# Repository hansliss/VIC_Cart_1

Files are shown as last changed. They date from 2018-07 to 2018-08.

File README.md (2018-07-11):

# VIC_Cart_1
A basic programmable RAM/ROM expansion for VIC-20

RAM is handled by an KM681000CLG-5L, 128kx8 static RAM
~RAM1,~RAM2,~RAM3 are NAND:ed together, so the 3k area is handled as a single block
A0-A13 are provided by the cartridge port, while A14 and A15 are connected to ~BLK2 and ~BLK1, respectively.
With 8k blocks (using 13 address lines)

NOTE: The RAM addressing is incorrect and needs to be fixed!

blk	addresses	
0	0400-0fff       01111  01
1	2000-3fff	10111  11
2	4000-5fff	11011  00
3	6000-7fff	11101  01
5	a000-bfff	11110  11

U4C: 3-input AND
U5D: 2-input OR

BLK0 OR BLK2 OR BLK3 = A13
BLK2 = A14

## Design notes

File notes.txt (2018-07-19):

C1: https://www.elfa.se/en/capacitor-100-nf-25-vdc-0603-rnd-components-rnd-1500603y104z250nt/p/30086612
C2, C3: https://www.elfa.se/en/capacitor-22-pf-50-vdc-0603-rnd-components-rnd-1500603n220f500nt/p/30086539
C4: https://www.elfa.se/en/aluminium-electrolytic-capacitor-10-uf-16-20-hc-panasonic-industry-europe-eeehc1c100r/p/30108103
C5-C11: https://www.elfa.se/en/capacitor-uf-16-0603-kemet-c0603x104k4ractu/p/30111165
D1: https://www.elfa.se/en/small-signal-diode-do-213aa-diotec-bav103/p/30110670
R1-R3: https://www.elfa.se/en/smd-resistor-metal-thin-film-10-kohm-panasonic-industry-europe-era3aeb103v/p/16015687
U4: https://www.elfa.se/en/logic-ic-so-16-sn74hc148-texas-instruments-sn74hc148d/p/17379828
U5, U6: https://www.elfa.se/en/logic-ic-so-14-nxp-74hc21d/p/17390727
U7,U8,U9: https://www.elfa.se/en/logic-ic-so-14-sn74hc32-texas-instruments-sn74hc32dr/p/30023025
Y1: https://www.elfa.se/en/quartz-hc49us-16-mhz-auris-16-00000m-hc49us-30-30-d32/p/17452832

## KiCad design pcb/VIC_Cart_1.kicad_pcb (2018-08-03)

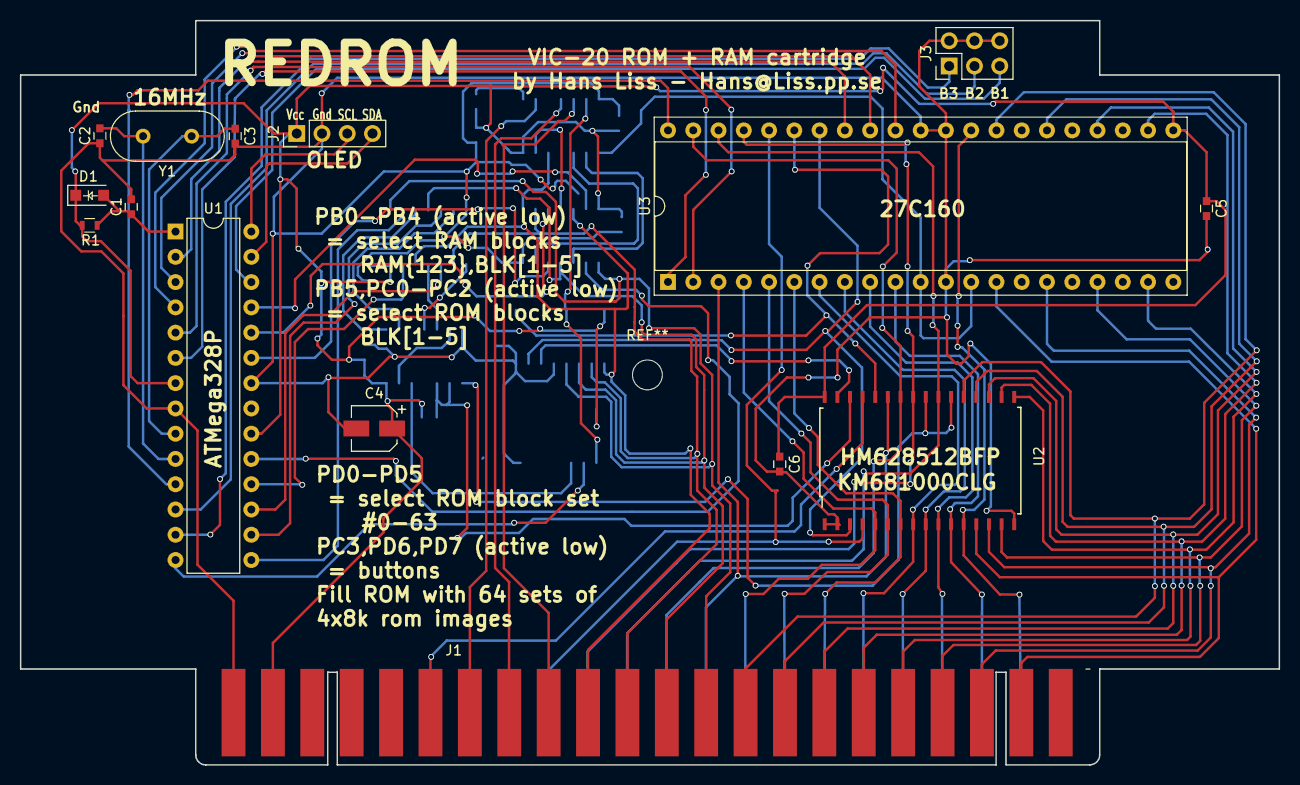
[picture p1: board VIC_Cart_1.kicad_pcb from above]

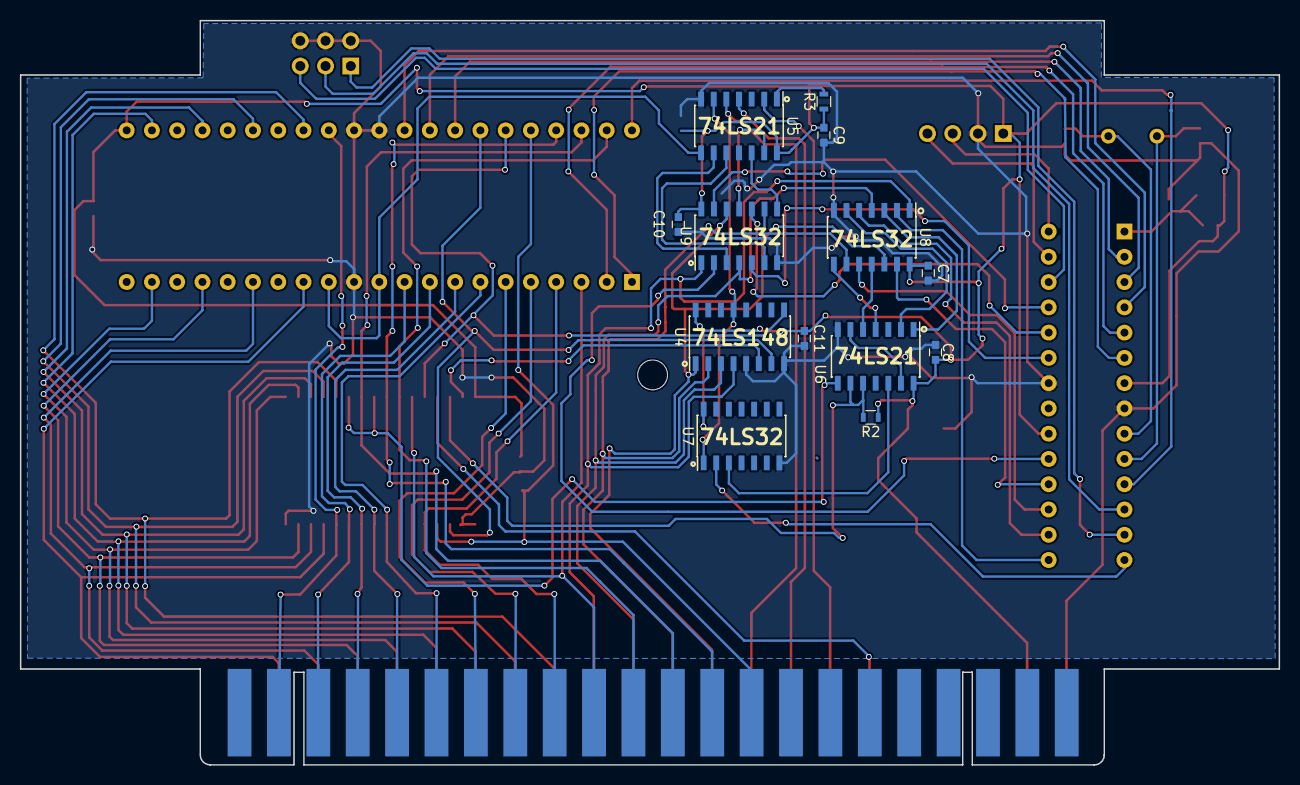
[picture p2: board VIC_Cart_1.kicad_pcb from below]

Board: 2 copper layers, 126.5 x 74.8 mm, 28 parts (13 on the bottom side), 72 nets.

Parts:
C1: 100nf; C_0603
C2, C3: 22pf; C_0603
C4: 10uf; CP_Elec_4x5.8
C5, C6, C7, C8, C9, C10, C11: 0.1uf; C_0603
D1: 1N4148; D_SOD-123F
J1: VIC-20_Expansion_Port; VIC_EXP
J2: I2C Display; Pin_Header_Straight_1x04_Pitch2.54mm
J3: Buttons; Pin_Header_Straight_2x03_Pitch2.54mm
R1, R2, R3: 10k; R_0603
U1: ATMEGA328P-PU; DIP-28_W7.62mm
U2: HM628512BFP-5; SOP-32_14.12x20.87mm_Pitch1.27mm
U3: M27C160; DIP-42_W15.24mm_Socket
U4: 74LS148; SOIC-16_3.9x9.9mm_Pitch1.27mm
U5, U6: 74LS21; SOIC-14_3.9x8.7mm_Pitch1.27mm
U7, U8, U9: 74LS32; SOIC-14_3.9x8.7mm_Pitch1.27mm
Y1: 16MHz; Crystal_HC49-4H_Vertical

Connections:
/OLED_SCL: J2.3, U1.28
/OLED_SDA: J2.4, U1.27
/V_RW: J1.17, U2.29
/~BLK1: J1.10, U4.4, U8.1, U9.1
/~BLK2: J1.11, U4.3, U8.4, U9.4
/~BLK3: J1.12, U4.2, U8.9, U9.9
/~BLK5: J1.13, U4.1, U8.12, U9.12
/~BUTTON1: J3.5, U1.26
/~BUTTON2: J3.3, U1.12
/~BUTTON3: J3.1, U1.13
/~RAM: U4.13, U5.6, U7.1
/~RESET: C1.1, D1.2, R1.2, U1.1
/~SEL_RAM_3k: U1.14, U7.2
/~SEL_RAM_BLK1: U1.15, U8.2
/~SEL_RAM_BLK2: U1.16, U8.5
/~SEL_RAM_BLK3: U1.17, U8.10
/~SEL_RAM_BLK5: U1.18, U8.13
/~SEL_ROM_BLK1: U1.19, U9.2
/~SEL_ROM_BLK2: U1.23, U9.5
/~SEL_ROM_BLK3: U1.24, U9.10
/~SEL_ROM_BLK5: U1.25, U9.13
A0: J1.B, U2.12, U3.30
A1: J1.C, U2.11, U3.10
A2: J1.D, U2.10, U3.9
A3: J1.E, U2.9, U3.8
A4: J1.F, U2.8, U3.7
A5: J1.H, U2.7, U3.6
A6: J1.J, U2.6, U3.5
A7: J1.K, U2.5, U3.4
A8: J1.L, U2.27, U3.3
A9: J1.M, U2.26, U3.41
A10: J1.N, U2.23, U3.40
A11: J1.P, U2.25, U3.39
A12: J1.R, U2.4, U3.38
BA0: U2.28, U3.37, U4.9
BA1: U2.3, U3.36, U4.7
BA2: U2.31, U4.6
D0: J1.2, U2.13, U3.14
D1: J1.3, U2.14, U3.16
D2: J1.4, U2.15, U3.18
D3: J1.5, U2.17, U3.20
D4: J1.6, U2.18, U3.23
D5: J1.7, U2.19, U3.25
D6: J1.8, U2.20, U3.27
D7: J1.9, U2.21, U3.29
GND: C1.2, C2.1, C3.2, C4.2, C5.2, C6.2, C7.2, C8.2, C9.2, C10.2, C11.2, J1.22, J2.2, J3.2, J3.4, J3.6, U1.8, U1.22, U2.1, U2.2, U2.16, U3.12, U3.31, U3.32, U4.5, U4.8, U5.7, U6.7, U7.7, U8.7, U9.7
unnamed: C2.2, U1.10, Y1.2
unnamed: C3.1, U1.9, Y1.1
unnamed: J1.14, U5.5
unnamed: J1.15, U5.4
unnamed: J1.16, U5.2
unnamed: R2.2, U2.30, U6.9, U6.10
unnamed: R3.2, U5.1
unnamed: U2.22, U2.24, U6.8
unnamed: U3.11, U3.13, U5.8
unnamed: U5.9, U9.3
unnamed: U5.10, U9.6
unnamed: U5.12, U9.8
unnamed: U5.13, U9.11
unnamed: U6.1, U8.3
unnamed: U6.2, U8.6
unnamed: U6.4, U8.8
unnamed: U6.5, U8.11
unnamed: U6.12, U7.3
unnamed: U6.6, U6.13
RB0: U1.2, U3.35
RB1: U1.3, U3.34
RB2: U1.4, U3.33
RB3: U1.5, U3.2
RB4: U1.6, U3.1
RB5: U1.11, U3.42
VCC: C4.1, C5.1, C6.1, C7.1, C8.1, C9.1, C10.1, C11.1, D1.1, J1.21, J2.1, R1.1, R2.1, R3.1, U1.7, U1.20, U2.32, U3.22, U4.16, U5.14, U6.14, U7.14, U8.14, U9.14

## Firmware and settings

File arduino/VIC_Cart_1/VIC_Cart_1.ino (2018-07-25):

#include <Adafruit_GFX.h>
#include <Adafruit_SPITFT.h>
#include <Adafruit_SPITFT_Macros.h>
#include <gfxfont.h>
#include <EEPROM.h>

#include <Adafruit_SSD1306.h>


int ram0=8;
int ram1=9;
int ram2=10;
int ram3=11;
int ram5=12;

int rom1=13;
int rom2=14;
int rom3=15;
int rom5=16;

int rb0=0;
int rb1=1;
int rb2=2;
int rb3=3;
int rb4=4;
int rb5=5;

int but1=17;
int but2=6;
int but3=7;

unsigned long debounceDelay = 100;

int rammode=0;

// OLED display TWI address
#define OLED_ADDR   0x3C

// reset pin not used on 4-pin OLED module
Adafruit_SSD1306 display(-1);  // -1 = no reset pin

// 128 x 64 pixel display
#if (SSD1306_LCDHEIGHT != 64)
#error("Height incorrect, please fix Adafruit_SSD1306.h!");
#endif

int ramModes[][2] = {
  {0, 0},
  {3, 1},
  {8, 2},
  {11,3},
  {16,6},
  {19,7},
  {24,14},
  {27,15},
  {32,30},
  {35,31}
};

int numRamModes=(sizeof(ramModes)/sizeof(int[2]));

int currentRamMode=0;

int setRamMode(int mode) {
  static int lastMode=-1;
  int bits=ramModes[mode][1];
  if (mode != lastMode) {
    lastMode=mode;
    EEPROM.write(0, mode);
    digitalWrite(ram0, (bits & 1)?LOW:HIGH); // outputs are active low!
    digitalWrite(ram1, (bits & 2)?LOW:HIGH);
    digitalWrite(ram2, (bits & 4)?LOW:HIGH);
    digitalWrite(ram3, (bits & 8)?LOW:HIGH);
    digitalWrite(ram5, (bits & 16)?LOW:HIGH);
  }
}

struct rm_s {
  char *text;
  int bits;
} romModes[]= {
  {"None", 0},
  {"BLK2,3", 6},
  {"BLK5", 8},
  {"BLK1,5", 9},
  {"BLK3", 4},
  {"BLK3,5", 12}
};

int numRomModes=(sizeof(romModes)/sizeof(struct rm_s));

int currentRomMode=0;

int setRomMode(int mode) {
  static int lastMode=-1;
  int bits=romModes[mode].bits;
  if (mode != lastMode) {
    lastMode=mode;
    EEPROM.write(1, mode);
    digitalWrite(rom1, (bits & 1)?LOW:HIGH); // outputs are active low!
    digitalWrite(rom2, (bits & 2)?LOW:HIGH);
    digitalWrite(rom3, (bits & 4)?LOW:HIGH);
    digitalWrite(rom5, (bits & 8)?LOW:HIGH);
  }
}

int numRomBanks=9;
int currentRomBank=0;

int setRomBank(int bank) {
  static int lastBank=-1;
  if (bank != lastBank) {
    lastBank=bank;
    EEPROM.write(2, bank);
    digitalWrite(rb0, (bank & 1)?HIGH:LOW); // outputs are active low!
    digitalWrite(rb1, (bank & 2)?HIGH:LOW);
    digitalWrite(rb2, (bank & 4)?HIGH:LOW);
    digitalWrite(rb3, (bank & 8)?HIGH:LOW);
    digitalWrite(rb4, (bank & 16)?HIGH:LOW);
    digitalWrite(rb5, (bank & 32)?HIGH:LOW);
  }
}

void displayModes() {
    static char buf[16];
    int ramSize=ramModes[currentRamMode][0];
    char *romConf=romModes[currentRomMode].text;
    display.clearDisplay();
    display.setTextSize(1);
    display.setTextColor(WHITE);
    display.setCursor(27,10);
    sprintf(buf, "RAM: %dkB", ramSize);
    display.print(buf);
    display.setCursor(27,20);
    sprintf(buf, "ROM: %s", romConf);
    display.print(buf);
    display.setCursor(27,30);
    sprintf(buf, "Bank: %d", currentRomBank);
    display.print(buf);
    display.display();
}

void setup() {
  currentRamMode = EEPROM.read(0);
  currentRomMode = EEPROM.read(1);
  currentRomBank = EEPROM.read(2);
  pinMode(ram0, OUTPUT);
  pinMode(ram1, OUTPUT);
  pinMode(ram2, OUTPUT);
  pinMode(ram3, OUTPUT);
  pinMode(ram5, OUTPUT);
  pinMode(rom1, OUTPUT);
  pinMode(rom2, OUTPUT);
  pinMode(rom3, OUTPUT);
  pinMode(rom5, OUTPUT);
  pinMode(rb0, OUTPUT);
  pinMode(rb1, OUTPUT);
  pinMode(rb2, OUTPUT);
  pinMode(rb3, OUTPUT);
  pinMode(rb4, OUTPUT);
  pinMode(rb5, OUTPUT);
  pinMode(but1, INPUT_PULLUP);
  pinMode(but2, INPUT_PULLUP);
  pinMode(but3, INPUT_PULLUP);
  digitalWrite(rom1, HIGH);
  digitalWrite(rom2, HIGH);
  digitalWrite(rom3, HIGH);
  digitalWrite(rom5, HIGH);
  // put your setup code here, to run once:
  display.begin(SSD1306_SWITCHCAPVCC, 0x3C);
  display.clearDisplay();
  display.display();
  setRamMode(currentRamMode);
  setRomMode(currentRomMode);
  setRomBank(currentRomBank);
  displayModes();
}

int buttonWithDeBounce(int button, int *curState, long *lastTime) {
  int r=0;
  int reading = digitalRead(button);
  if ((millis() - *lastTime) > debounceDelay) {
    if (reading != *curState) {
      *curState=reading;
      r = (*curState == LOW);
      *lastTime = millis();
    }
  }
  return r;
}

void loop() {
  static int but1State=HIGH;
  static int but2State=HIGH;
  static int but3State=HIGH;
  static long lastDebounceTimeBut1=0;
  static long lastDebounceTimeBut2=0;
  static long lastDebounceTimeBut3=0;
  if (buttonWithDeBounce(but1, &but1State, &lastDebounceTimeBut1)) {
    currentRamMode = (currentRamMode + 1) % numRamModes;
    setRamMode(currentRamMode);
    displayModes();
  }
  if (buttonWithDeBounce(but2, &but2State, &lastDebounceTimeBut2)) {
    currentRomMode = (currentRomMode + 1) % numRomModes;
    setRomMode(currentRomMode);
    displayModes();
  }
  if (buttonWithDeBounce(but3, &but3State, &lastDebounceTimeBut3)) {
    currentRomBank = (currentRomBank + 1) % numRomBanks;
    setRomBank(currentRomBank);
    displayModes();
  }
}

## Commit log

2018-07-10 Initial import
    [VIC_Cart_1-B.Cu.gbr, VIC_Cart_1-B.Paste.gbr, VIC_Cart_1-B.SilkS.gbr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]
2018-07-11 Added A13/A14 to RAM for correct block addressing
    [VIC_Cart_1-B.Cu.gbr, VIC_Cart_1-B.Fab.gbr, VIC_Cart_1-B.Mask.gbr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]
2018-07-11 Working on the RAM addressing scheme - currently incorrect
    [VIC_Cart_1.sch]
2018-07-13 Massive redesign to fix block address encoding from the expansion port signals
    [VIC_Cart_1-B.Cu.gbr, VIC_Cart_1-B.Fab.gbr, VIC_Cart_1-B.Mask.gbr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]
2018-07-13 Added Connectors lib Cleaned up libs by removing unused components
2018-07-13 Added Footprint library to project Added explanatory text to PCB
    [VIC_Cart_1-B.Cu.gbr, VIC_Cart_1-B.Fab.gbr, VIC_Cart_1-B.Mask.gbr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]
2018-07-14 Added back ground plane
    [VIC_Cart_1-B.Cu.gbr, VIC_Cart_1-B.Fab.gbr, VIC_Cart_1-B.Mask.gbr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]
2018-07-14 Switched around BLK[1-5] to encoder to put ROM blocks in correct order.
    [VIC_Cart_1-B.Cu.gbr, VIC_Cart_1-B.Fab.gbr, VIC_Cart_1-B.Mask.gbr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]
2018-07-17 Minor change
    [VIC_Cart_1-B.Cu.gbr, VIC_Cart_1-B.Fab.gbr, VIC_Cart_1-B.Mask.gbr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]
2018-07-17 Moved PCB files to subdirectory
    [VIC_Cart_1-B.Cu.gbr, VIC_Cart_1-B.Fab.gbr, VIC_Cart_1-B.Mask.gbr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]
2018-07-24 Arduino code added
2018-07-29 Changed pads to pin header footprint for buttons Inverted BLK inputs to encoder to correct addressing error Added component values to silkscreen
    [VIC_Cart_1-B.CrtYd.gbr, VIC_Cart_1-B.Cu.gbr, VIC_Cart_1-B.Fab.gbr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]
2018-07-29 No change
    [VIC_Cart_1.kicad_pcb, VIC_Cart_1.sch]
2018-07-31 Added mounting hole Added title
    [VIC_Cart_1-B.CrtYd.gbr, VIC_Cart_1-B.Cu.gbr, VIC_Cart_1-B.Fab.gbr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]
2018-07-31 Moved button pin header to the right Changed outline to match existing (large) carts, e.g. 16k expansion
    [VIC_Cart_1-B.CrtYd.gbr, VIC_Cart_1-B.Cu.gbr, VIC_Cart_1-B.Fab.gbr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]
2018-07-31 Changed silkscreen text
    [VIC_Cart_1-B.CrtYd.gbr, VIC_Cart_1-B.Cu.gbr, VIC_Cart_1-B.Fab.gbr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]
2018-08-03 Moved capacitor to back Grounded A17, A18 for 512k RAM Added RAM chip to project lib
    [VIC_Cart_1-B.Adhes.gbr, VIC_Cart_1-B.CrtYd.gbr, VIC_Cart_1-B.Cu.gbr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]
